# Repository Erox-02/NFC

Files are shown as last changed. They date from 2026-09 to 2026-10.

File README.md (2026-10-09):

# NFC

A basic nfc card with custom antenna .

## Design 

The integrated planar antenna harvests power from the phone's magnetic field to  light up the led placed in front side pcb layer while simltaniously doing nfc connection with phone/other device . Also i have left some traces for later i2c uses .

### Back 

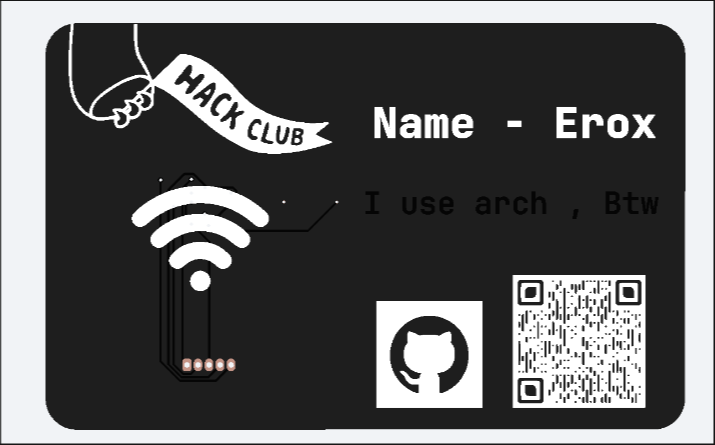
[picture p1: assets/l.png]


### Front

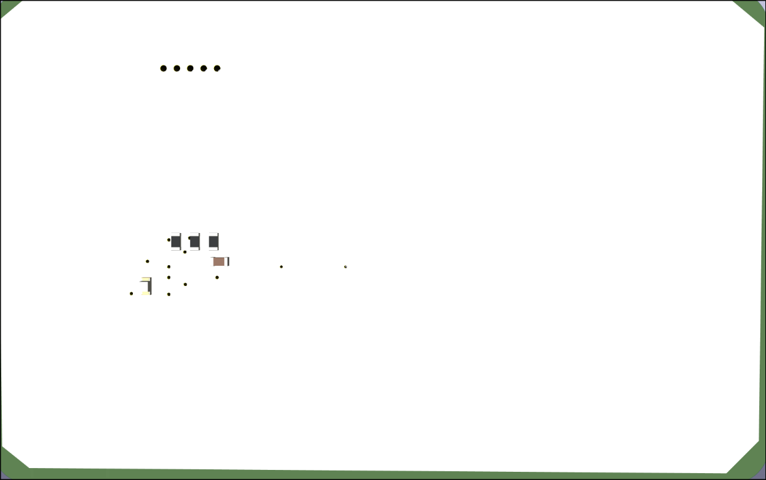
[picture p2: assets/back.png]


## How to make your own pcb?

Check out my project's build video's on forge 

[Forge](https://forge.hackclub.com/projects/2851)

you can re use my antenna and add custom footprint for others , or you can swap my name and qr with your own :D .

## Building The nfc  

I will use pcba on jlc pcb to order it because the parts are kinda rare in india and if i order frm lcsc , it will cost me more for shipping and moq .

But if you wanna solder/rework on your own , order the parts frm given links in bom and solder the components on the designated places as cpl.xlsx says , then connect the card with your nfc enabled phone and bind a url . Or you can use a esp 32/other mpu and rewrite the eeprom with i2c , **REMINDER : USE 2.2-3v POWER SUPPLY **

detailed steps for non pcba :

- Order the components listed in the bom.
- Place the components according to the xlsx file(use jlcpcb's pcba tool to mark things up with the cpl ).
- Solder the components onto the pcb.
- Bring the completed card near an nfc phone.
- Configure the ic with the  data.

The antenna is supposed to harvest energy from the nfc field,
which is more than enough to power the led while the nfc ic communicates
with the phone or whatever nfc device youre using.

## Credits 

- > [LINK]{https://neurotech-hub.github.io/KiCad-Antenna-Generator/}

- Kicad

## Author 

me , mineself Erox aka Dipanjan  

# BOM 

| Designator | Comment | Footprint | Quantity | LCSC Part # | LCSC Link | Unit Price |
|---|---|---|---:|---|---|---:|
| Cap1 | 180 nf | Capacitor_SMD:C_0603_1608Metric | 1 | C519440 | https://www.lcsc.com/product-detail/C519440.html | $0.0114 |
| D1 | LED | LED_0603_1608Metric | 1 | C19171394 | https://www.lcsc.com/product-detail/C19171394.html | See LCSC |
| R1 | 5k ohm | Resistor_SMD:R_0603_1608Metric | 1 | C862232 | https://www.lcsc.com/product-detail/Chip-Resistor-Surface-Mount_YAGEO-RT0603BRE075KL_C862232.html | $0.0293 |
| R2 | 5k ohm | Resistor_SMD:R_0603_1608Metric | 1 | C862232 | https://www.lcsc.com/product-detail/Chip-Resistor-Surface-Mount_YAGEO-RT0603BRE075KL_C862232.html | $0.0293 |
| R3 | 5k ohm | Resistor_SMD:R_0603_1608Metric | 1 | C862232 | https://www.lcsc.com/product-detail/Chip-Resistor-Surface-Mount_YAGEO-RT0603BRE075KL_C862232.html | $0.0293 |
| U1 | NT3H2111W0FHKH | XQFN-8_L1.6-W1.6-P0.50-BL_NT3H2111W0FHKH | 1 | C710403 | https://www.lcsc.com/product-detail/NFC-RFID-Tags_NXP-Semiconductors-NT3H2111W0FHKH_C710403.html | $0.6224 |

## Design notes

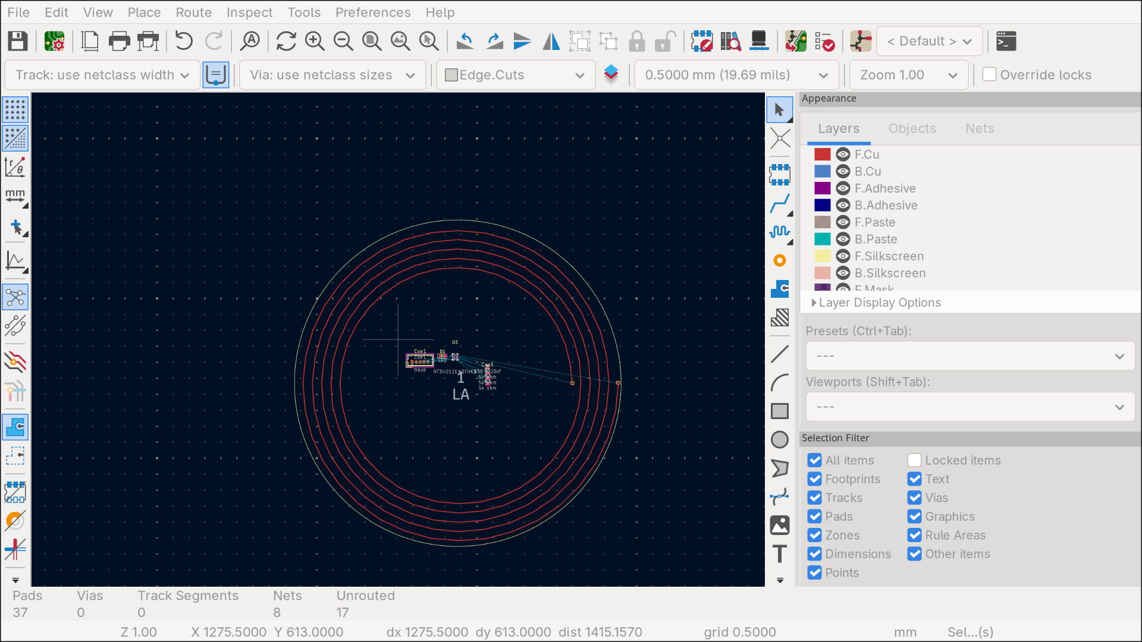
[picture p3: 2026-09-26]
assets/ftprnt.png

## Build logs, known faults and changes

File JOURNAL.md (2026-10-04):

---
title: "My-nfc"
author: "Erox"
description: "Just my nfc card "
created_at: "2026-09-25"
---

# Sept 25 : 

Ok so for my nfc card today i started the work , i chose `NT3H2111` this ic for my work , i think i will use the eeprom for nfc on my card and i2c for rewrittin when needed , ik i can use the nfc for rewrittin but why tht when i can just use i2c .

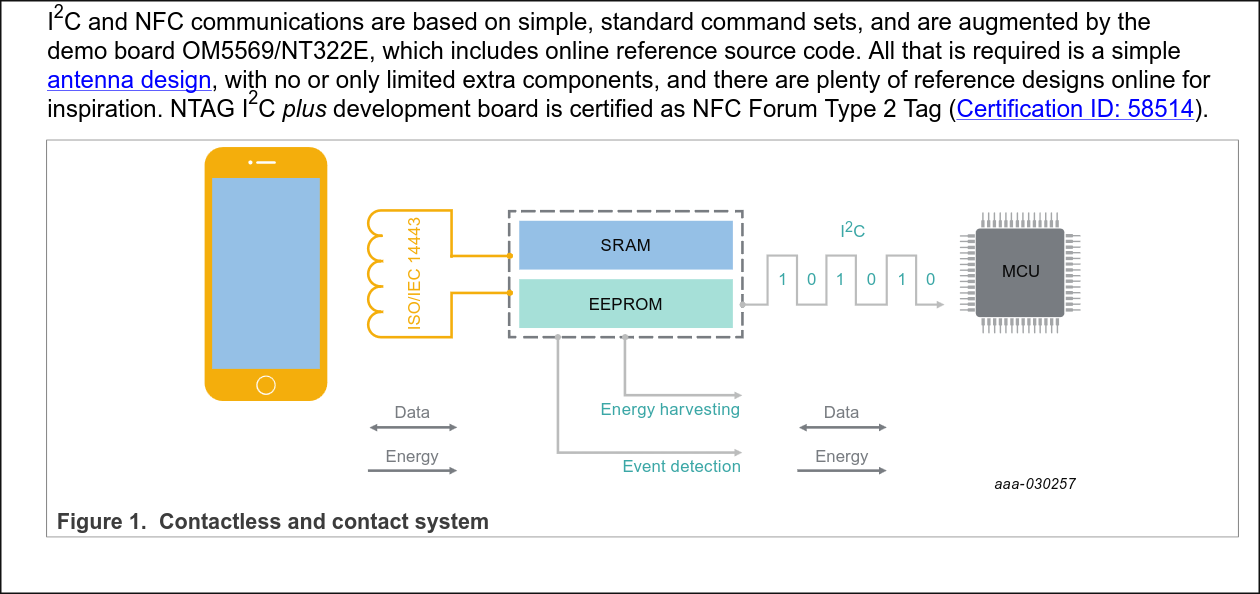
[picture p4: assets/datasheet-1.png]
Datasheet img


 2 kb is far more than enough for storing just some links , like my portfolio , my github or even my phone num also i can use it as a card access if i use rfid sensors later but thts upto the later me not now at all so why worry? 

 Oh so its a sot902 qfn not a prob for me i have got hot air hehe .

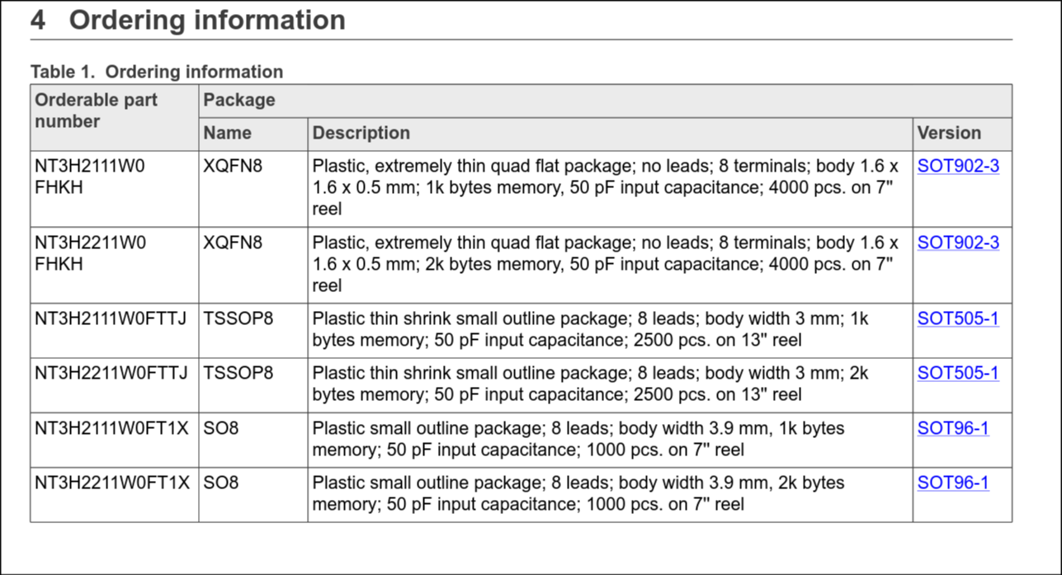
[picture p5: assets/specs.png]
 

 Lol too bad for windows users but i use arch btw with easyeda2kicad from yay i got the footprints and symbols of lcsc , but as i am kind guy , i will tag those in my repo .

Wait i just realized its qfn even with a hot air its hard , oh its hard bring it on i will do it mysef .

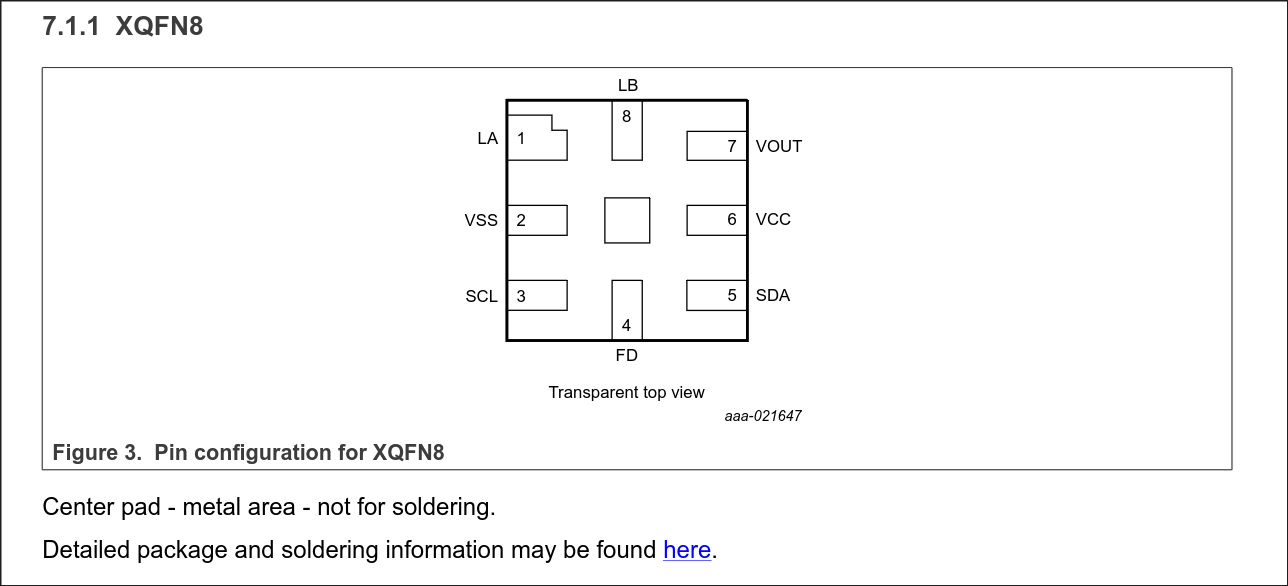
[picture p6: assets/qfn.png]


          A
          |
This is the pic of the qfn ic

ok so started the schematics , added the symbols , made a extra trace for later i2c use on the nt3 .

ah man i dont wanna go around and find the logic voltage in the datasheet , wait i dont need to actually , i2c operates at 3.3v .

Oh just found gold in the datasheet i can use the vout to power a led when i use the card , amazing right? lets do tht

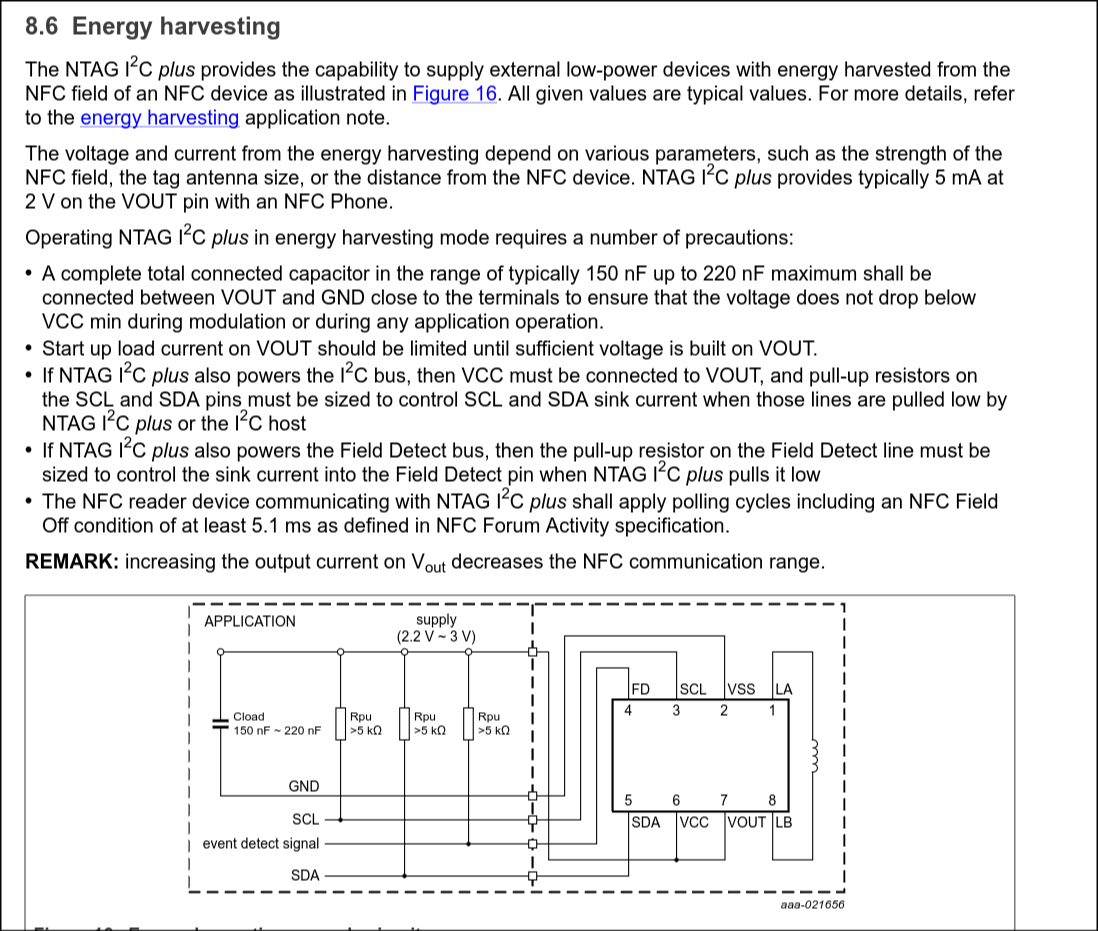
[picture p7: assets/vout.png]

the thing i got frm datasheet .

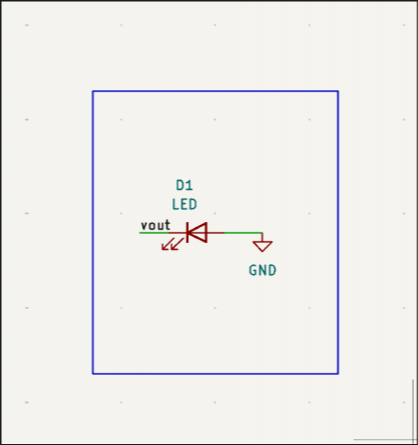
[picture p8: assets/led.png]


ok added a led but but its just a ultra frank design obviously i will add res and cap after measuring current and vol frm the vout .

actually we can control tht but why worry now , thts for later not now at all .

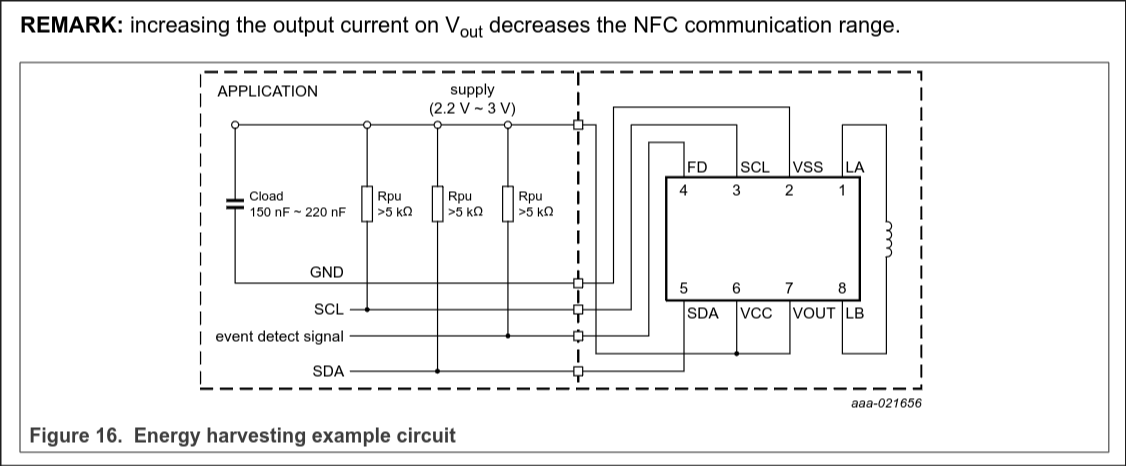
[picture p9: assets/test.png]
 ===> this is the test circuit givn in the datasheet maybe i will use it . 

**Total time spent: 1 hours**

# Sept 26 :

Today i started readin the datasheet and placed res and caps , fixed the values accordingly to the datasheet now it looks much better .

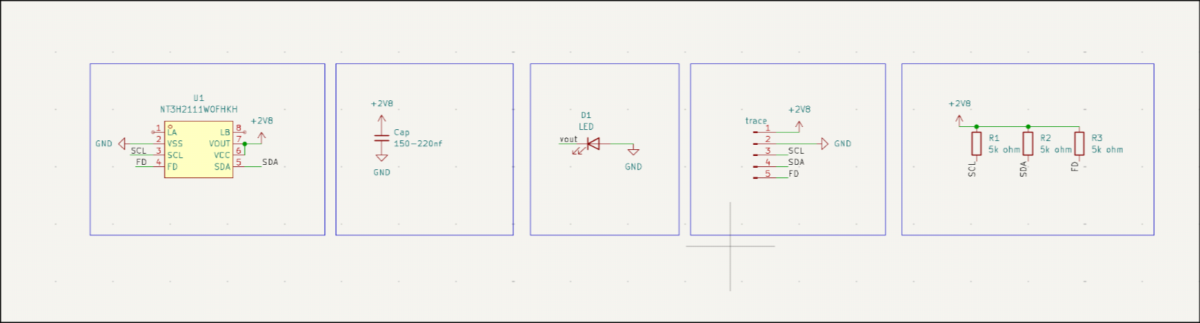
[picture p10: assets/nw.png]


Also for lapse , reviewers plz dont mind my music .

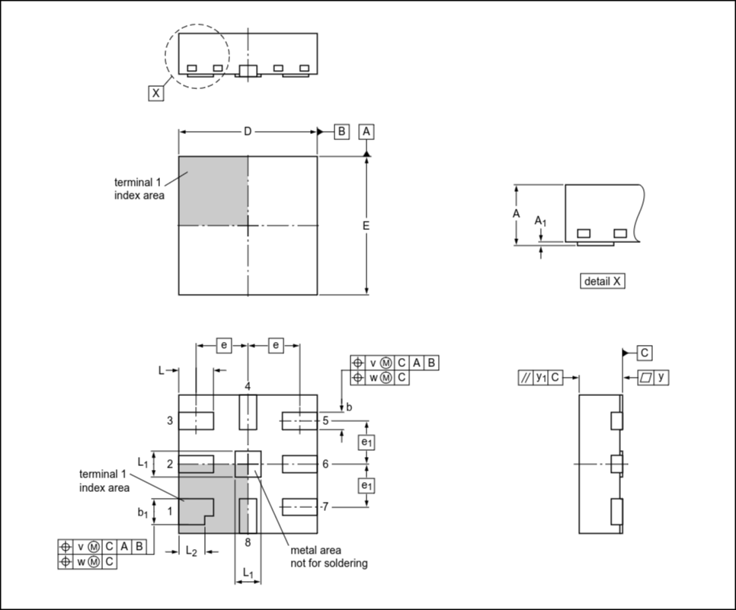
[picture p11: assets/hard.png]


Its gonna be really hard to work on , my hot air shld do it still .

the datasheet doesnt have any desc abt the antenna , dont tell me i need to do tht myself , ah .

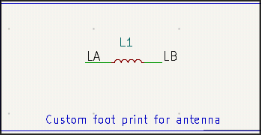
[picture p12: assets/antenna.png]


added the sym for antenna , now the real pain , custom footprint . 
got the idea how to make an antenna now just needa calculate the dimensions .

Shld i use lambda/4 for this one? 

Ok google said i shldnt use tht , i shld use 1/(2.pie(lc)^1/2) one , shld be easy . 

WAIT how the hell am i supposed to calculate the ind of the trace?

i got a good calculator , and as i am using 1 oz , it shld be 35 um , i shld verify .

ok verified but i also got a tool to make it instead of making it myself buhaha .

its `https://neurotech-hub.github.io/KiCad-Antenna-Generator/`

ok now needa find inductence .

Oh done 

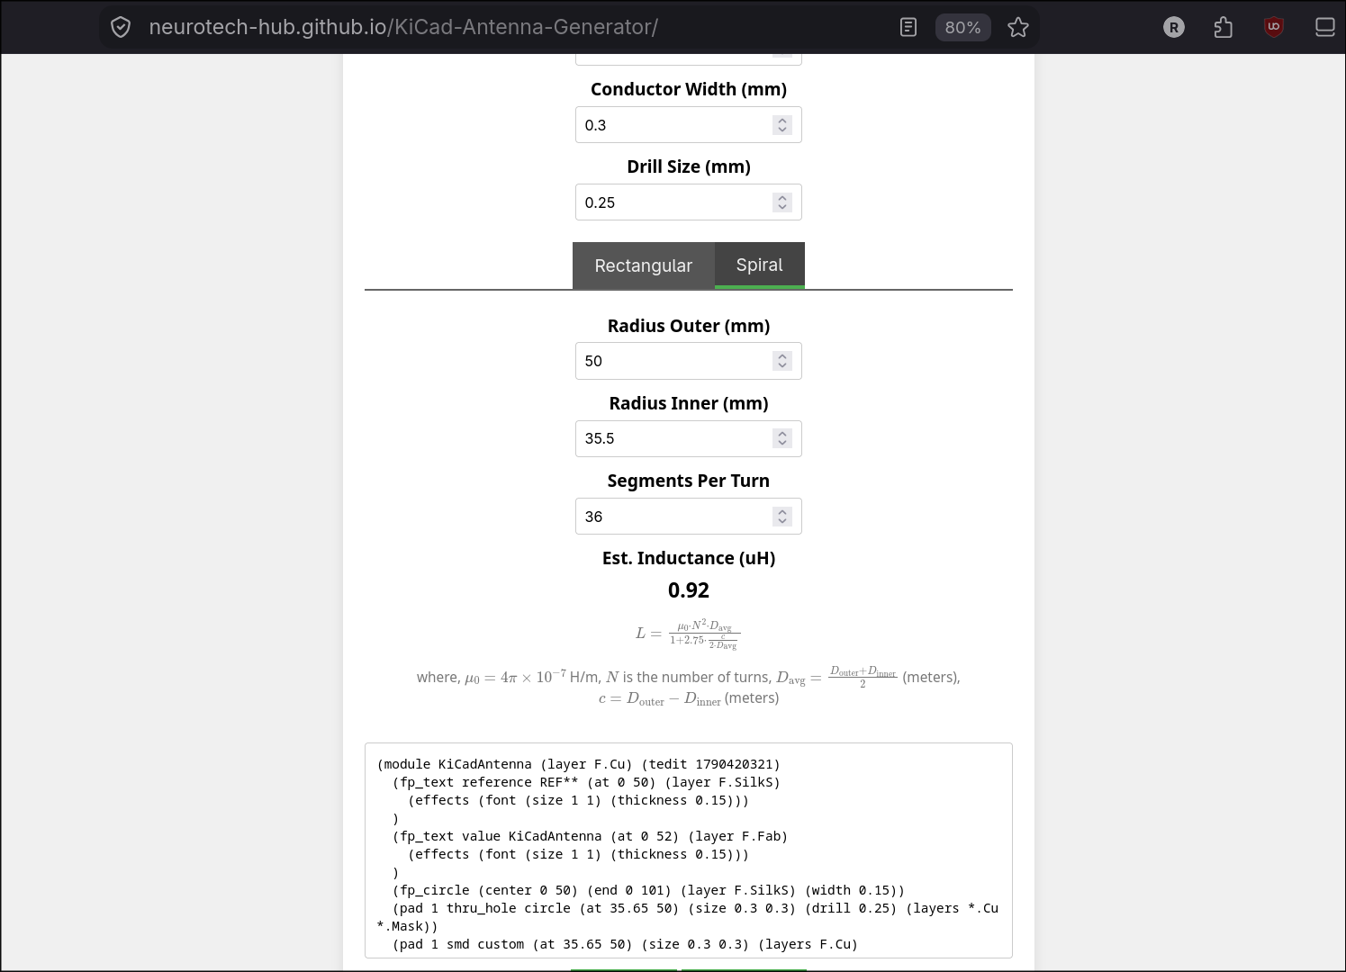
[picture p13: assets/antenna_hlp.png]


this site saved my ass , now i have the footprint , i can easily do the rest .

done lol 

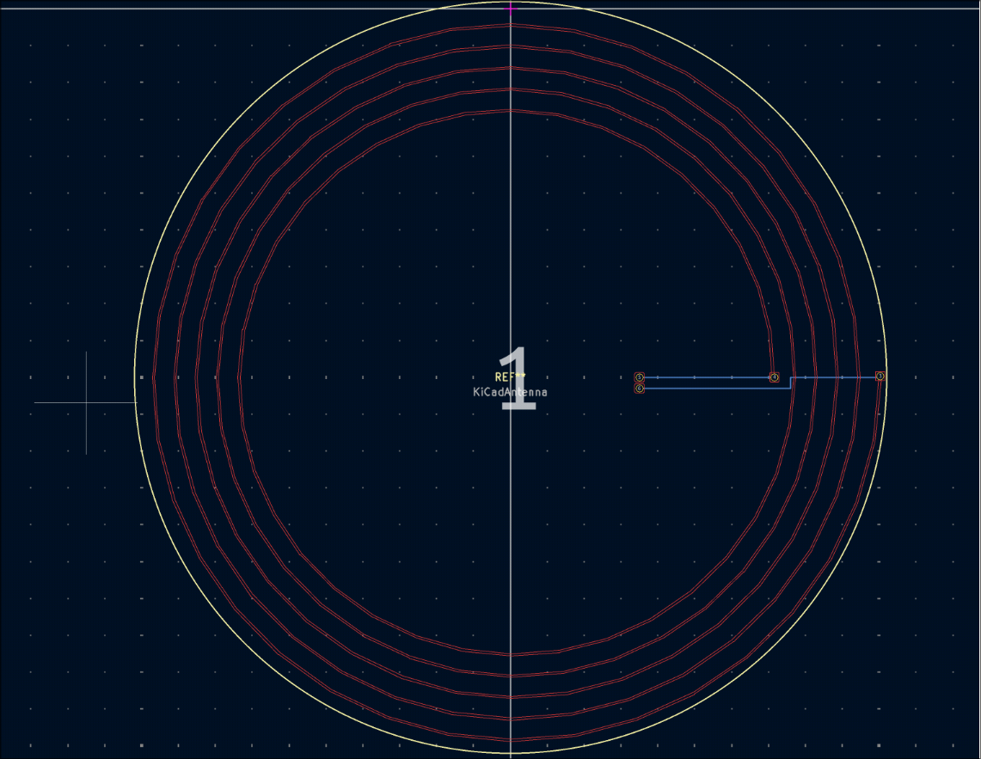
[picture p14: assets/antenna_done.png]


it was far easier than i thought .

i started the pcb and used the antenna footprint but after i made changes to the footprint and saved tht , now i just cant use the new footprint idk why?

ok fixed but i just realized , the footprint is way too bigger , i mistook diameter with radius ahhhhh wtf.

ah now footprint err

ok fixed eerything now time for connecting things , 

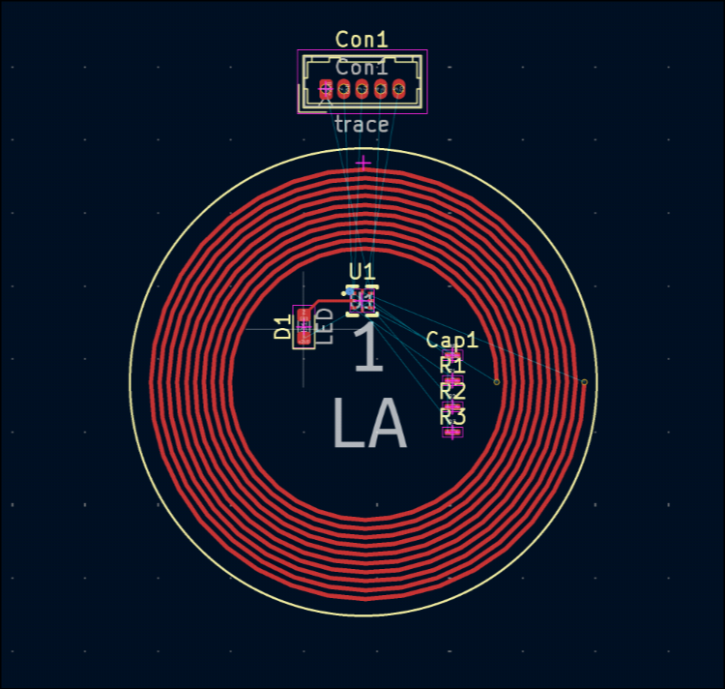
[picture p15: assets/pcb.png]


looks like the nfc tag itself is complete uf finally .

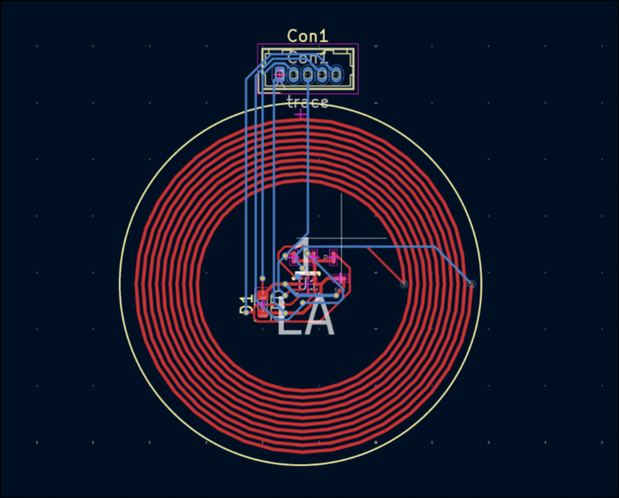
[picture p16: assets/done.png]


ok its done now , now i need styles on it .

ok i will do tht later 

**Total time spent: 2.5 hours**

# Sept 27 :

today i started with the pcb qr and forgot to document lol . HOW DID I FORGOT to document?

ok anyways imma gonna dump the photos because i forgot to document , its probably the bad effect of lapse .

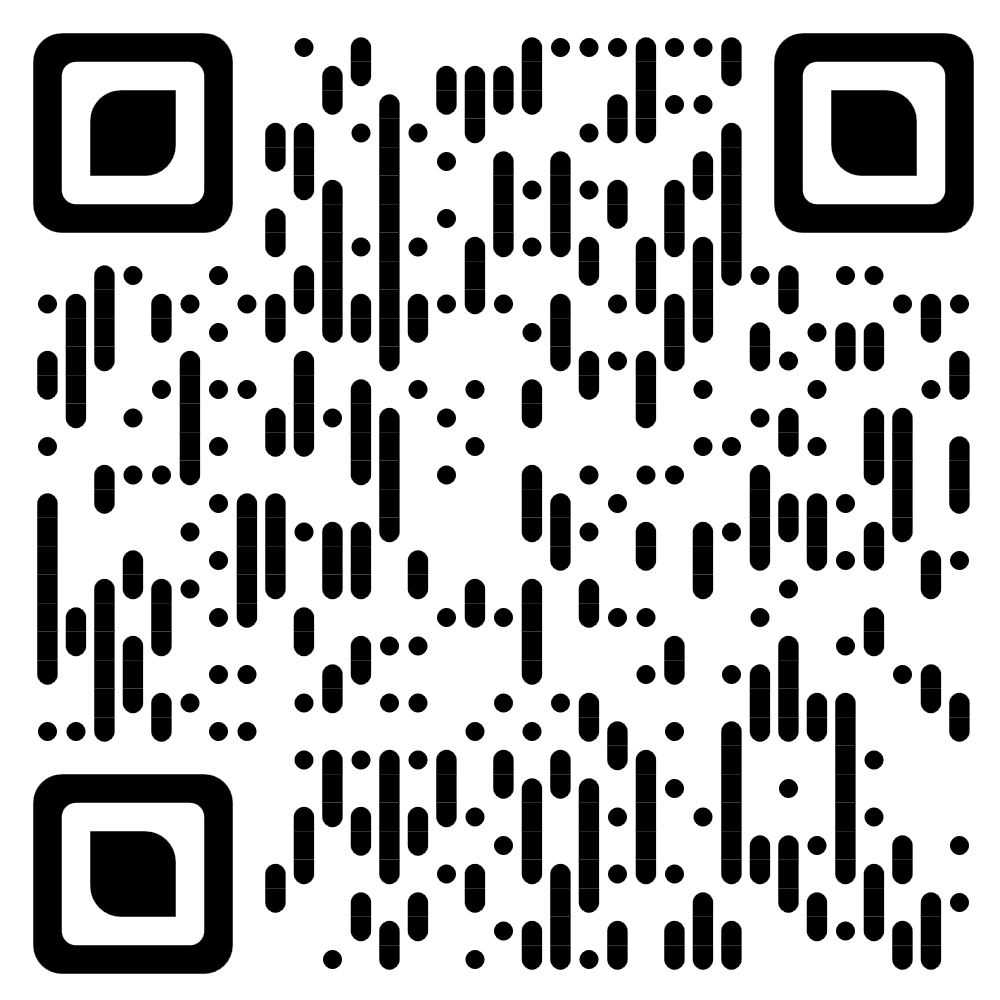
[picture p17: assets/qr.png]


now reversed one 

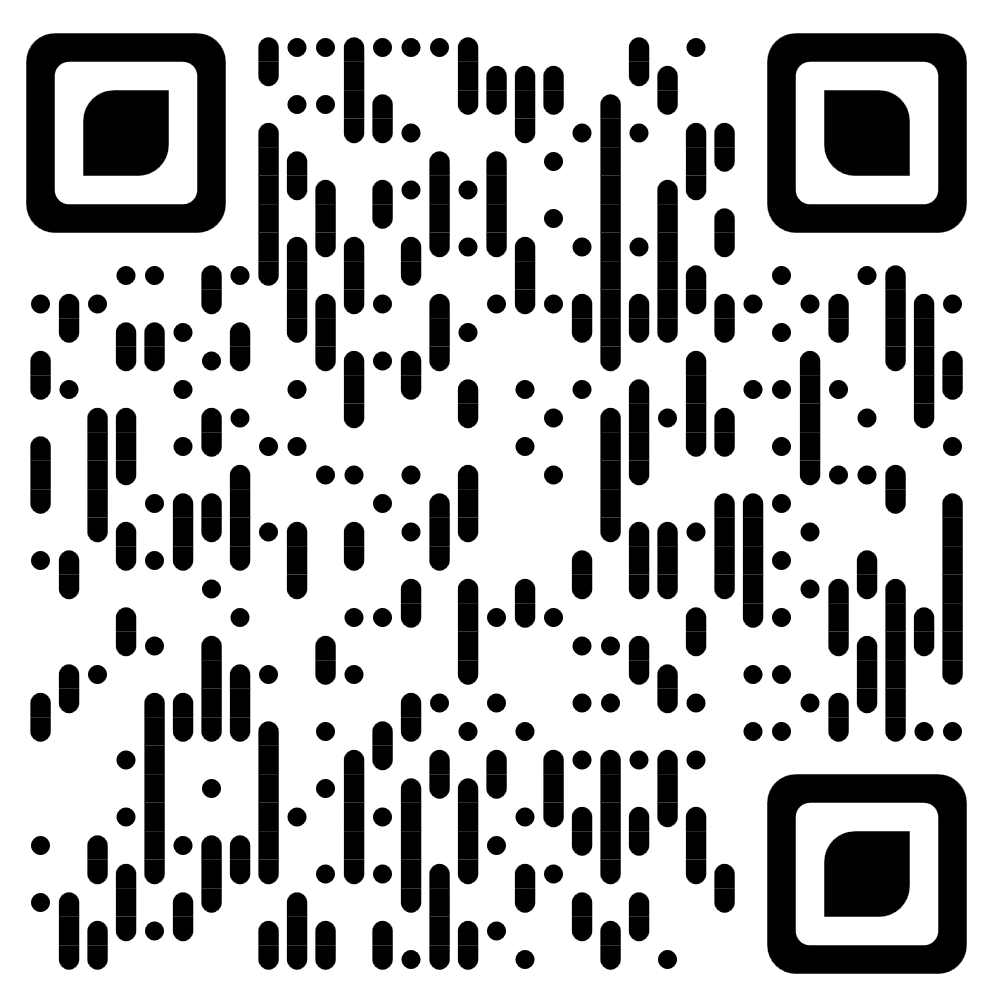
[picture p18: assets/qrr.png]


huh i just wrote this lil in hella so much time ?

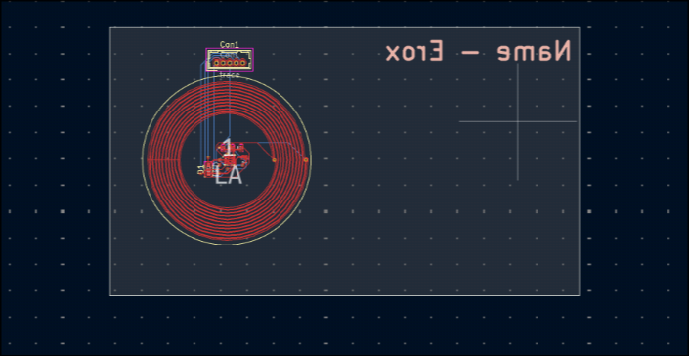
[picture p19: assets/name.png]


i just changed all the f.silks with b.silks in my qr code's .

HOLY SHIT WhY DIDNT I KNEW ABT IF I JUST FLIP , KICAD AUTO CHANGES , kill me .

ok anyways it done now for today

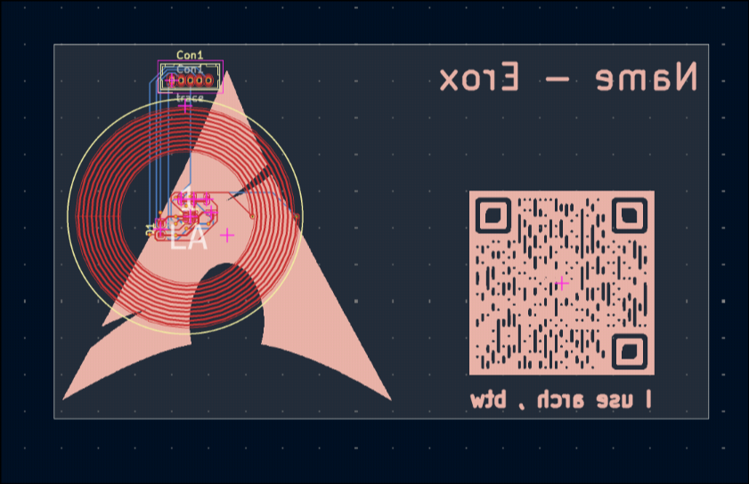
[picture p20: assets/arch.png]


these are the last pics , thx to lapse , i forgot to document my pain .

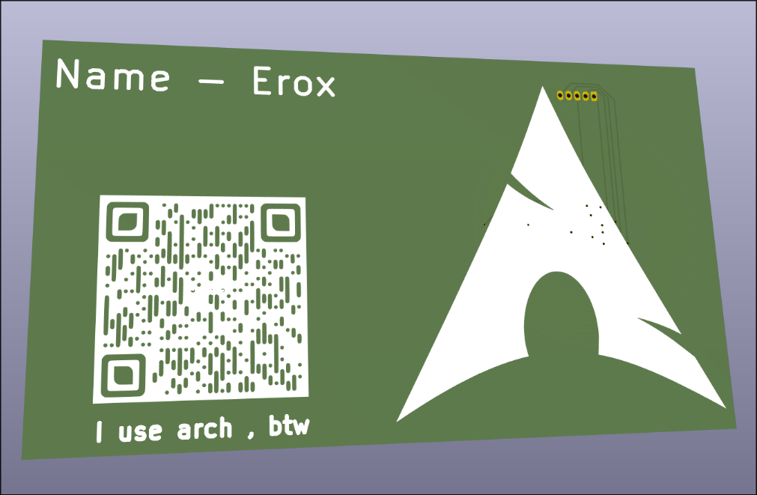
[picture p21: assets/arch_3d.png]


**Total time spent: 2 hours**

# Sept 28 and 29 :

last day i lost my streak because i was  mins late .

today i started with some design change (check lapse )

then i found with pcba i can do the things really cheap so its a good thing , now i need to remove the silkscreen, easy i just made it cover the whole board 

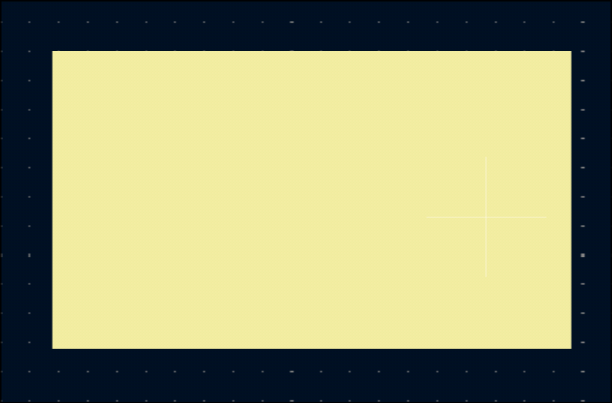
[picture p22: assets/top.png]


now the final view ,

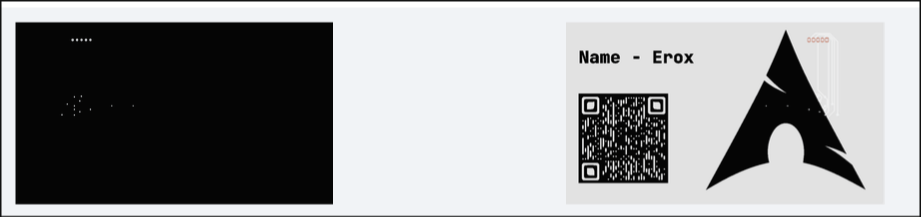
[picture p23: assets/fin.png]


heres it .

today i did some heavy lifting even before lapse , like fixin the logo , researching abt nf but i forgot to turn lapse on , lol

now the final touch done too , looks like this :
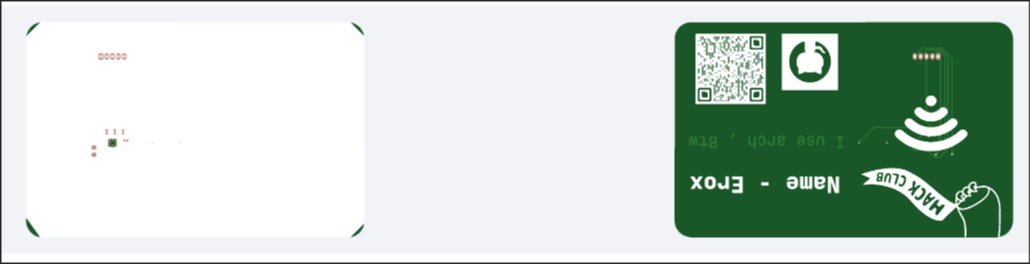
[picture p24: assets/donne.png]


and its done next is to make a bom for pcba in jlcpcb .

thts done too now , check lapse for details , done ::

**Total time spent: 2 hours**

# Sept 30 :

Today its the final journal of `NFC` in the software side as today imma gonna clear up some small things , change the res sizes(too hard to find 0402 in lcsc) same for the caps so imma gonna just update the pcb's footprint rather than dying on the once selected parts tht went extinct frm the cart right after i found them.

done changed the footprints 

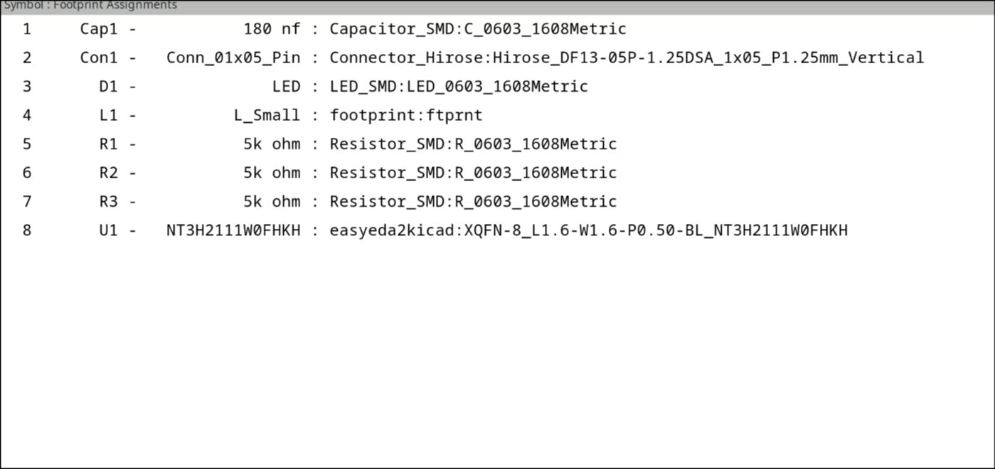
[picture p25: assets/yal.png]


ok so next imma gonna find the things , correct the bom and submit it right today wait its already after 12 am so today is pretty broad , isnt it?

done all found in lscs , now i can make the .csv 
done , positions set now whts next? oh uploading to jlc to get the cost  .

my bom and cpl is just so messed up , i fixed it again and again and then after fixing , jlc started giving me website timeout lol.

at last it worked and more suffering , so i though why not take a sc?

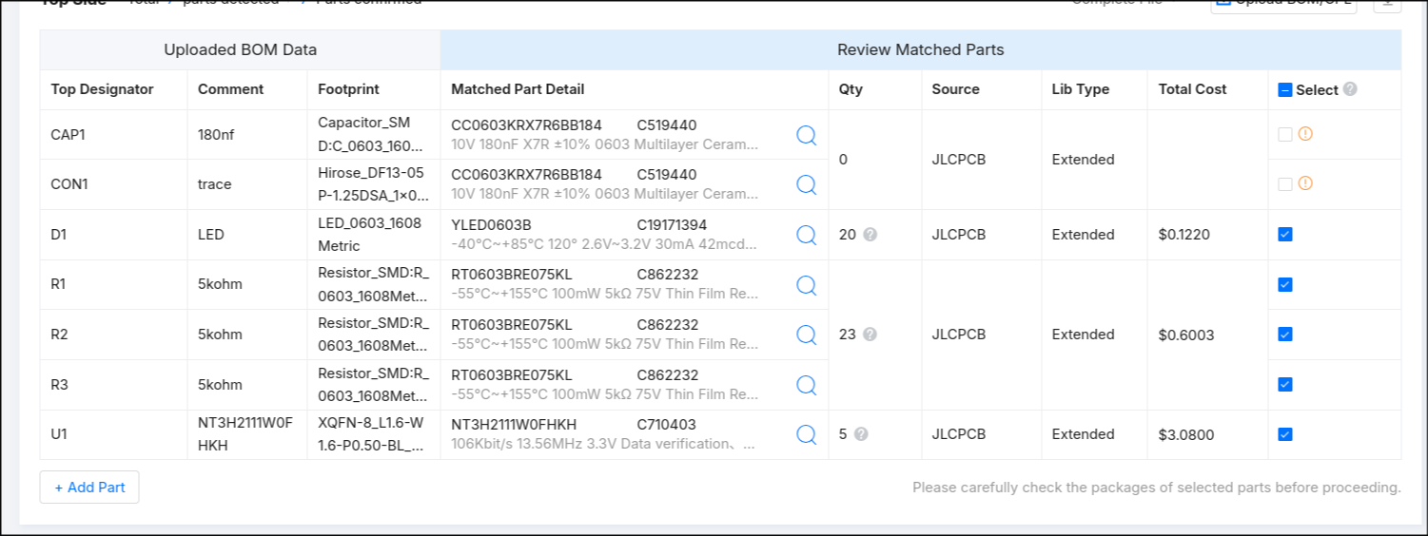
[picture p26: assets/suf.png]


next i fixed the files by removing the conn_01x05... as thts not a component .

done jlc accepted it holy , i am finally done its something like 27.58$ for 5x but wait i didnt chose thee colour .

i chosed the colours now lets restart the order 

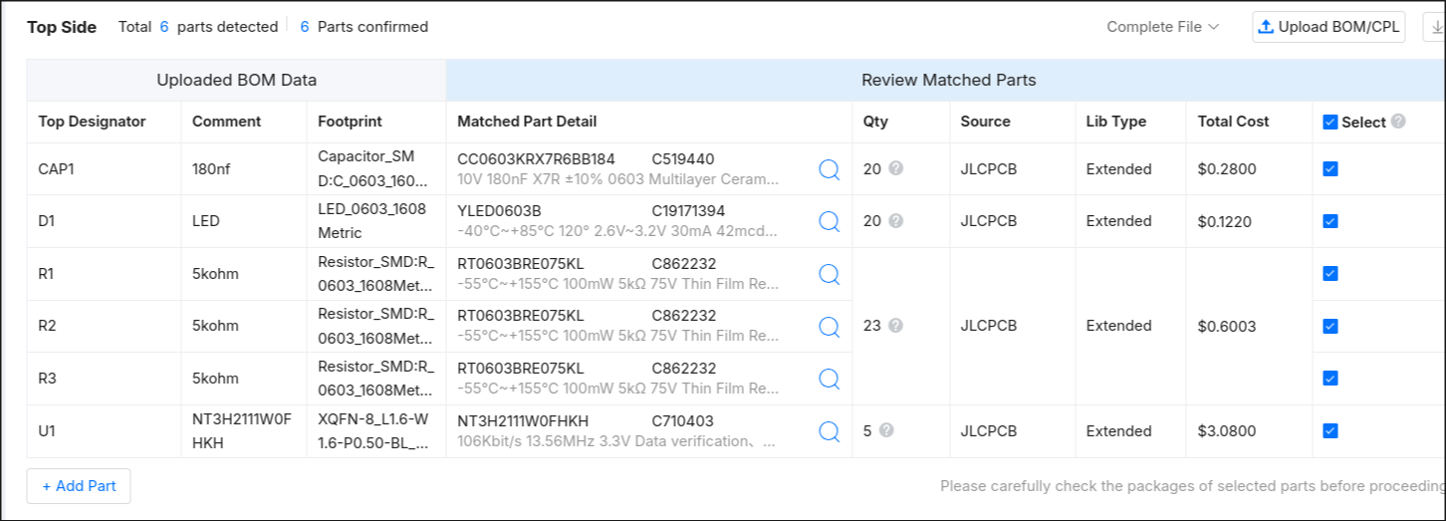
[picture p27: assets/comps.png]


component placement is fine too 

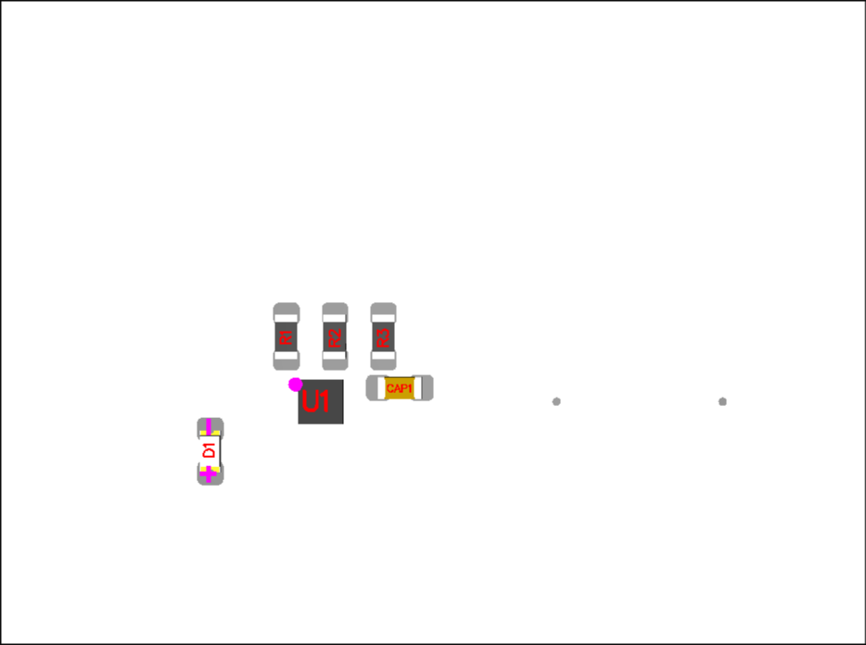
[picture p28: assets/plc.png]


looks like with the coupon i shld be able to buy it hm .

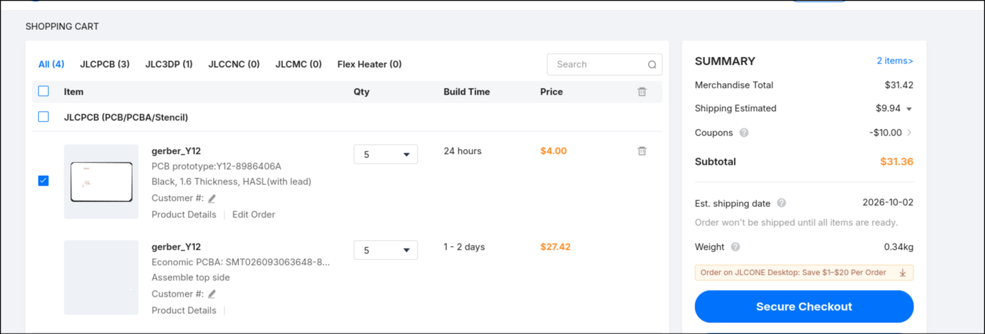
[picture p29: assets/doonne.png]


wait HOLY CRAP forgot to lapse today ahhhhhhhhhh.

**Total time spent: 1.5 hours** 

# Oct 3 : 

gonna write the readme today ->

Done now gonna submit in forge 

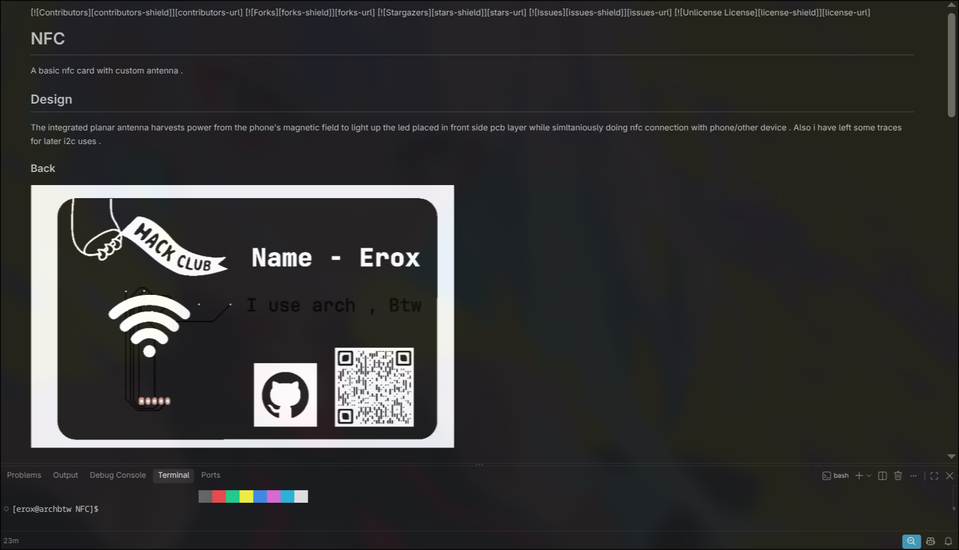
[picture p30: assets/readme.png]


Dont worry abt the links on the top , its gonna work on github normally 

**Total time spent: 1 hours**

# oct 4 :

i upgraded the readme as the reviewer said , changed the build section and added clear instructions , fixed the broken markdown .

:
---
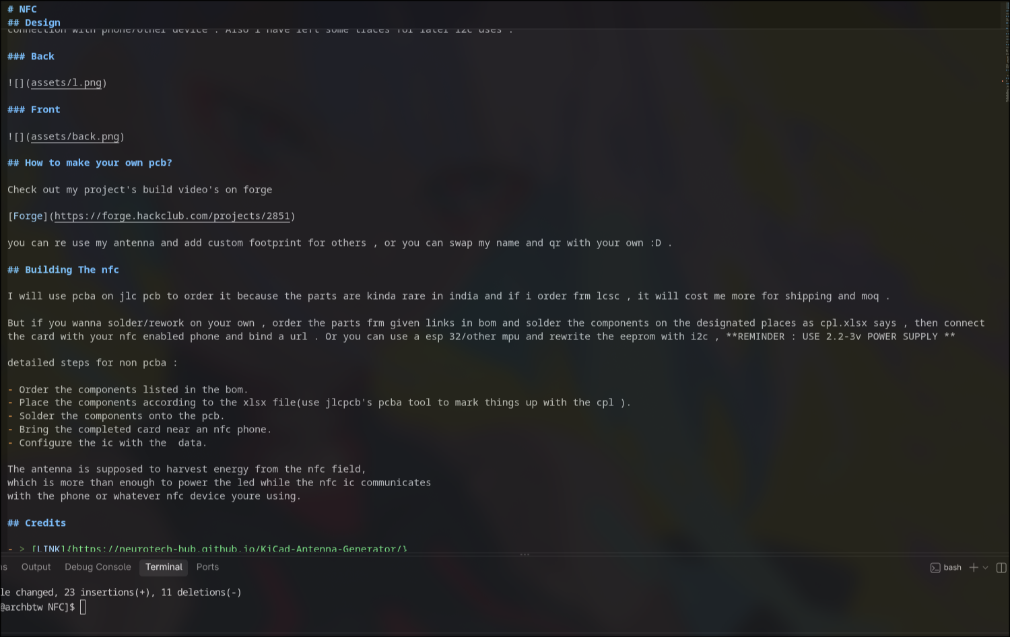
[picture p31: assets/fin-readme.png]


Now i can submit and sleep uff .

**Total time spent: 0.1 hours**

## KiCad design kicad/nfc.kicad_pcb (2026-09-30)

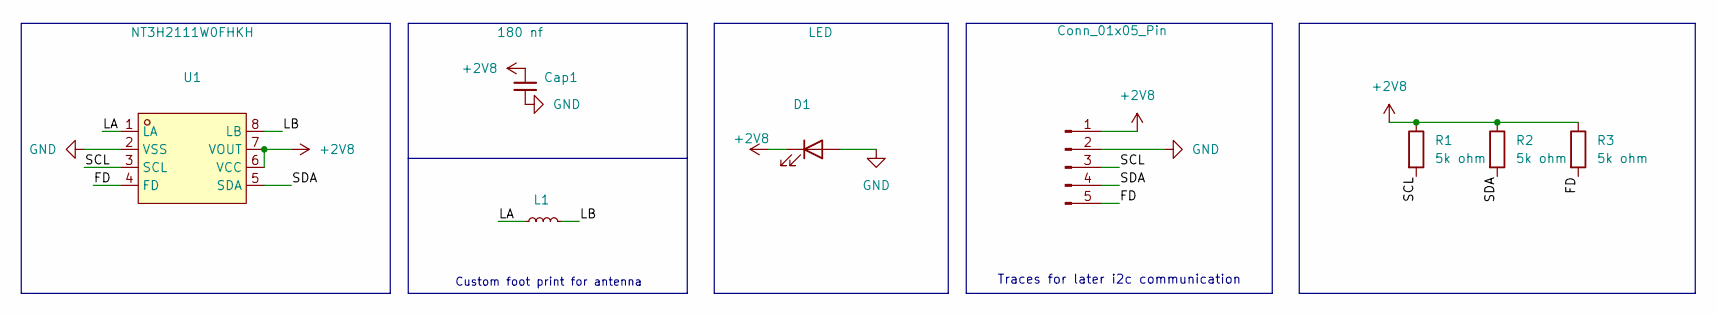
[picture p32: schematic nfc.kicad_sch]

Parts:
Cap1: 180 nf; C_0603_1608Metric
Con1: Conn_01x05_Pin; Hirose_DF13-05P-1.25DSA_1x05_P1.25mm_Vertical
D1: LED; LED_0603_1608Metric
L1: L_Small; ftprnt
R1, R2, R3: 5k ohm; R_0603_1608Metric
U1: NT3H2111W0FHKH; XQFN-8_L1.6-W1.6-P0.50-BL_NT3H2111W0FHKH; MPN NT3H2111W0FHKH; LCSC Part C710403

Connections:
+2V8: Cap1.1, Con1.1, D1.1 (K), R1.1, R2.1, R3.1, U1.6 (VCC), U1.7 (VOUT)
/FD: Con1.5, R3.2, U1.4 (FD)
/LA: L1.1, U1.1 (LA)
/LB: L1.2, U1.8 (LB)
/SCL: Con1.3, R1.2, U1.3 (SCL)
/SDA: Con1.4, R2.2, U1.5 (SDA)
GND: Cap1.2, Con1.2, D1.2 (A), U1.2 (VSS)

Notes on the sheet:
Traces for later i2c communication
Custom foot print for antenna

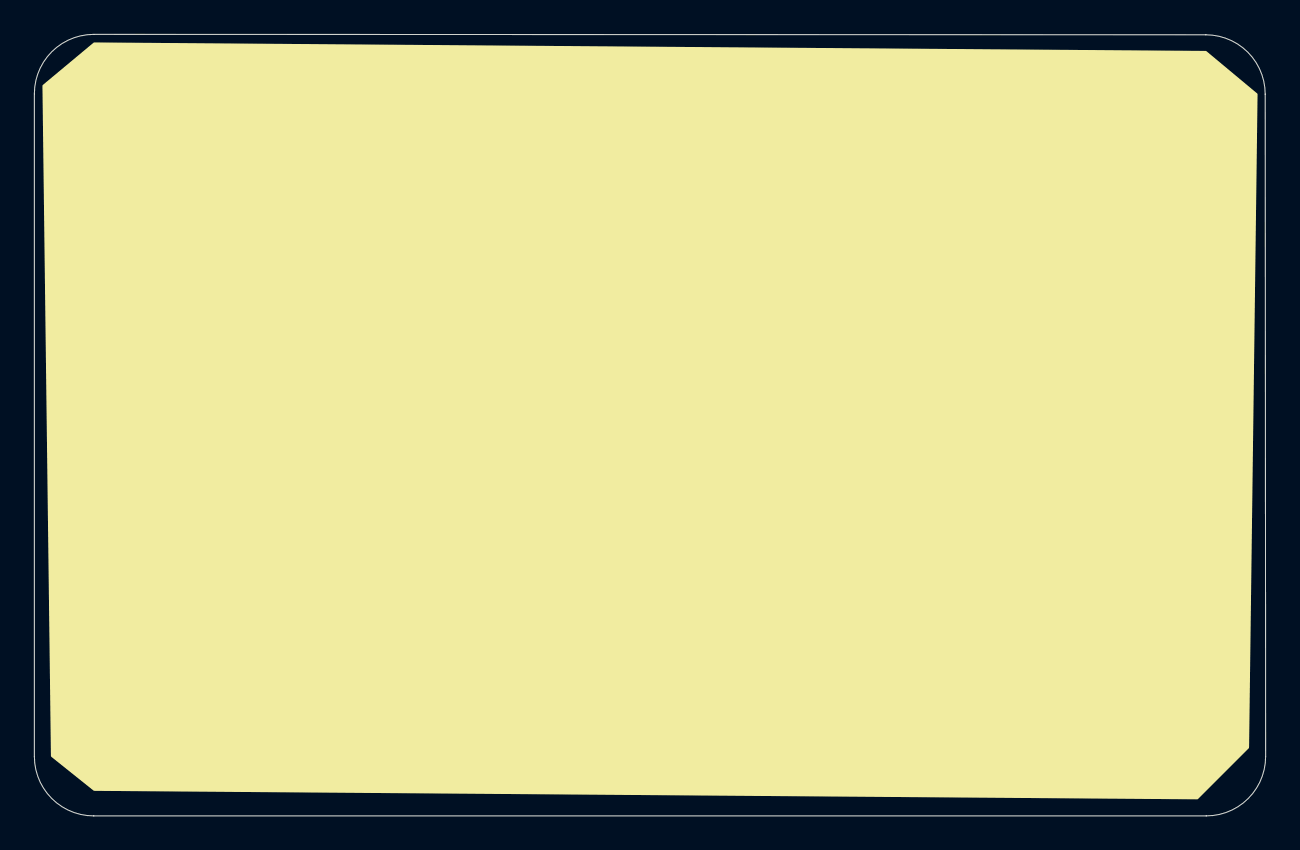
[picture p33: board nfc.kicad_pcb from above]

Board: 2 copper layers, 72.6 x 46.1 mm, 8 parts (0 on the bottom side), 7 nets.

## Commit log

2026-09-26 sept 26
    [nfc.kicad_pcb, nfc.kicad_sch]
2026-09-30 ok kinda done gonna tune right now again
    [BOM.csv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]
2026-10-03 readme done gonna ship now
    [BOM.csv]
